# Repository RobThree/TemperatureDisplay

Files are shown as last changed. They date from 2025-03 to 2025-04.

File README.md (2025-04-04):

#  Temperature Display

Uses an Wemos D1 mini with a GXHT30 I²C temperature & humidity sensor and a SSD1306 I²C 0.96" OLED display.

This project supports OTA updates, uses the WiFi manager to configure the WiFi and provides a REST API to get the temperature and humidity as JSON. The readings (and display) are updated every 2 seconds (by default, configurable) and also output to serial.

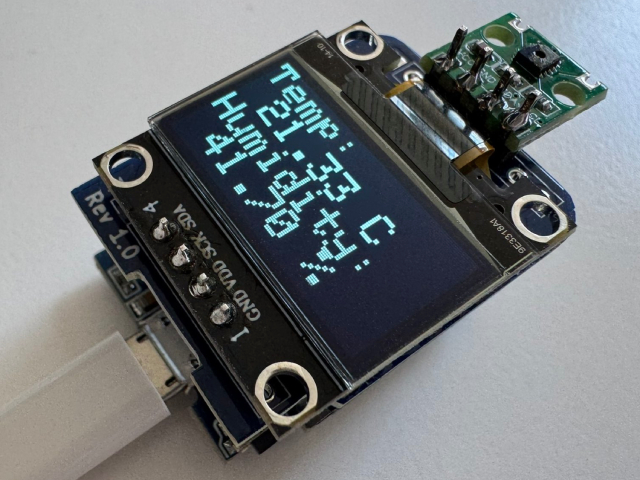
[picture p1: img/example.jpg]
Example


## Hardware

You'll need:

* [Wemos D1 mini or clone](https://aliexpress.com/w/wholesale-wemos-d1-mini.html)
* [GXHT30 I²C temperature & humidity sensor module](https://aliexpress.com/w/wholesale-GXHT30-module.html)
* [SSD1306 I²C 0.96" OLED display](https://aliexpress.com/w/wholesale-SSD1306-0.96%22.html)
* 2x [2.54mm female header 8 pins](https://aliexpress.com/w/wholesale-2.54mm-female-header-8-pins.html)
* 2x 8 pin and 2x 4 pin [2.54mm pin headers](https://aliexpress.com/w/wholesale-single-row-male-2.54mm.html)

All of these components are readily available at the time of writing, you should be able to easily source them.

### PCB

The [`pcb`](/pcb/) directory contains the KiCad (9.0) design files for the Wemos D1 mini shield PCB. [PCBWay](https://www.pcbway.com/) reached out to me and was kind enough to support this project. The project is available at [PCBWay's Shared Projects](https://www.pcbway.com/project/shareproject/Temperature_display_f0e459fd.html) for easy ordering.

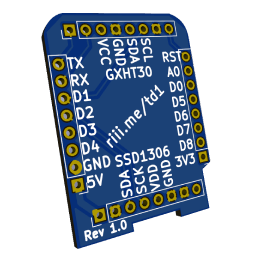
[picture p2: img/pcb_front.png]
PCB front
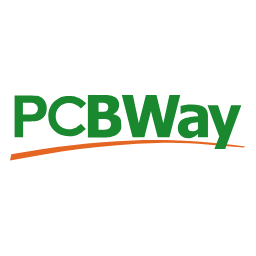
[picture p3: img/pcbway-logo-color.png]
PCBWay logo (https://www.pcbway.com/)
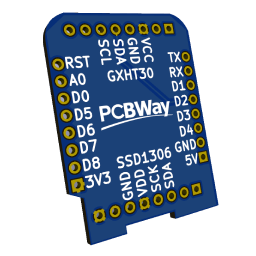
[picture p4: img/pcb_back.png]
PCB back
   

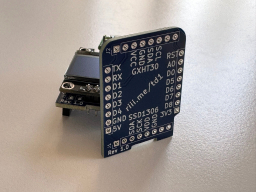
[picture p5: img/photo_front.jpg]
PCB front
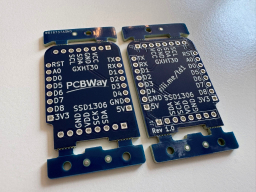
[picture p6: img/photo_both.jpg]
PCBWay logo
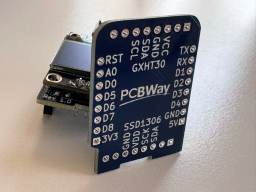
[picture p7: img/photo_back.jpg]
PCB back
   

For more pictures of the PCB and/or project see [the project page](https://www.pcbway.com/project/shareproject/Temperature_display_f0e459fd.html) or the [/img/PCBWay](/img/PCBWay/) directory. I would like to thank PCBWay again 🙏 Shipping was incredibly quick 🛫🛬 and the PCB is perfectly finished 👌

In a next iteration I'm hoping to integrate the GXHT30 on the shield, but being pretty new to PCB design this first iteration uses a module.

### DIY

Connect the GXHT30 and SSD1306 to the Wemos D1 mini's `3v3` pin, connect the grounds of all three modules. And connect `SDA` to `D2` (`GPIO4`) and `SCL` to `D1` (`GPIO5`). That's it. Done. Apparently some modules require 5V; if your display is glitching or not turning on, try connecting it to the 5V pin on the Wemos D1 mini. I power the project via the Wemos' onboard USB port but you should also be able to power it by directly powering the power pins.

```
                           +----------+        +------------------+
                           |  GXHT30  |        |     SSD1306      |
                           |    [X]   |        |                  |
                           |          |        |                  |
                           | V G  S S |        |    V  G  S  S    |
   +-----------------+     | C N  D C |        |    C  N  D  C    |
   |  Wemos D1 mini  |     | C D  A L |        |    C  D  A  K    |
   |    (ESP8266)    |     +----------+        +------------------+
   |                 |       | |  | |               |  |  |  |
   |              D1 |-------|-|--|-+---------------|--|--|--+
   |              D2 |-------|-|--+-----------------|--|--+
   |                 |       | |                    |  |
   |                 |       | |                    |  |
   |                 |       | |                    |  |
   |                 |       | |                    |  |
   |             GND |-------|-+--------------------|--+
+--| 3V3             |       |                      |
|  +-----------------+       |                      |
+----------------------------+----------------------+
```

### Tips on assembly:

* ⚠️ On some displays [there's a capacitor that can get quite close to the pins of this board](/img/pin.jpg). You might want to take a sidecutter and snip of a piece of the pin or use some kapton tape or some other means to isolate the pin. Make sure you check BOTH left and right side of the display!
* Solder the pinheaders/sockets **first**, and only **then** solder the display / temperature sensor. If you solder the display first you'll have a hard time reaching the pins connecting the board to the Wemos D1 mini
* When soldering the display to the board, [use a female header as a spacer](/img/spacer.jpg) for the perfect alignment.
* You don't _need_ to use male/female headers to connect the Wemos D1 mini to the PCB, you can use pins-only to make the device more compact. Just make sure you keep enough clearance!
* Don't forget to emjoy the peel-feel when removing the protective peel from the OLED 🤤

## Software

This is a PlatformIO project. I'm sure someone will help convert this to an Arduino IDE project, but it's not going to be me.

### How to get started

1. Open this folder in [PlatformIO for VSCode](https://platformio.org/platformio-ide)
2. Copy [`include/example_config.h`](include/example_config.h) to `include/config.h` and change the OTA update password and **devicename** (this one is optional)
3. Copy [`example_env_secrets.ini`](example_env_secrets.ini) to `env_secrets.ini` and set the same password for the `--auth` option
4. ⚠️ Make sure your [`platformio.ini`](platformio.ini) file has `default_envs` set to `d1_mini_serial`
5. Connect your USB cable to your device and the Wemos D1 mini
6. Compile the project and upload via (USB virtual) serial to your Wemos D1 mini
7. You should now be able to connect to a WiFi AP named after your **devicename** (see step 2); connect to it, set your WiFi credentials and save
8. The Wemos D1 mini should reboot and the OLED display should (shortly) show the IP; the display should show any other errors or problems as well
9. Next time you update you can use the OTA configuration (`default_envs` set to `d1_mini_ota` and the correct IP in `env_secrets.ini` at the `upload_port` entry), no more need for USB cables

### Once it's up and running

The display will show the temperature in °C or Fahrenheit (see `include/config.h`) and the humidity in %RH (Relative Humidity). If your sensor is way off you can fix this by setting `TEMPERATUREOFFSET` and/or `HUMIDITYOFFSET` in `include/config.h` and updating the device or, much easier, by using the web UI. The temperature and humidity will also be output to the serial port every time the sensor is read (see `UPDATEINTERVAL`) and when you use the `/read` endpoint of the REST API (e.g. `http://<deviceip>/read` [`GET`]) you'll get the readings as json:

```json
{
  "celsius": {
    "temperature": 22.81,
    "offset": -5
  },
  "fahrenheit": {
    "temperature": 73.058,
    "offset": -9
  },
  "humidity": {
    "relative_perc": 31.29,
    "relative_perc_offset": 8
  },
  "wifi": {
    "rssi": -48
  },
  "lastupdate": "1.62 seconds ago",
  "display": "c",
  "devicename": "MyDevice"
}
```

These values are only updated every time the sensor is read (again: see `UPDATEINTERVAL`). There is also a `/reset` endpoint ([`PUT`]) that will reboot the device.

Finally, the device also offers a user-friendly UI at the `/` endpoint (e.g. `http://<deivce-ip-here>/`) which updates every 5 seconds:

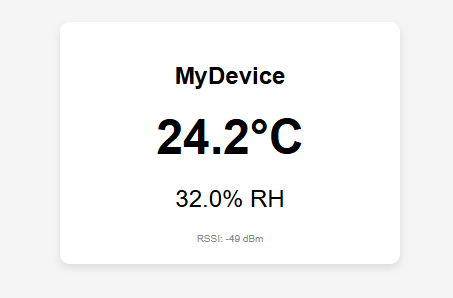
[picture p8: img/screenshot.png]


You can find the settings at `http://<deivce-ip-here>/settings` or by clicking the cog in the top right corner of the home screen. The settings screen allows you to adjust some values. Once your changed settings have been saved you can go back home by clicking the 'home' icon in the top right corner.

## Attribution

* PCB design based based on [Jérôme Labidurie](https://github.com/jerome-labidurie)'s [Wemos D1 mini Shield template for KiCad](https://github.com/jerome-labidurie/d1_mini_kicad)
* Logo from [SVG Repo](https://www.svgrepo.com/svg/179515/thermometer-temperature) (CC0 License)

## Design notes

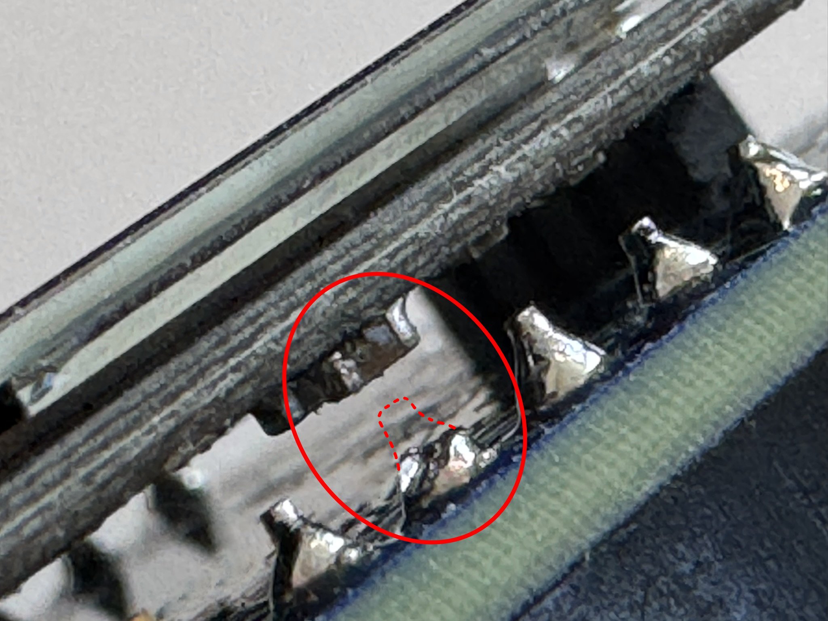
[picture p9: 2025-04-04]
img/pin.jpg

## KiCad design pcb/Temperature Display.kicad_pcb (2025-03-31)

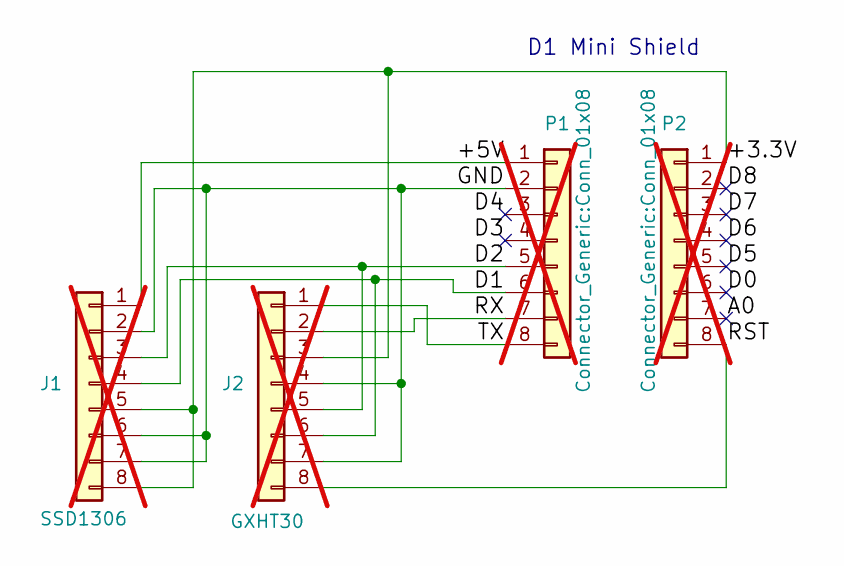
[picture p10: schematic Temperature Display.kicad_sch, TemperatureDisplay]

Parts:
J1: SSD1306; PinHeader_1x08_P2.54mm_Vertical; not fitted
J2: GXHT30; PinHeader_1x08_P2.54mm_Vertical; not fitted
P1, P2: Connector_Generic:Conn_01x08; PinHeader_1x08_P2.54mm_Vertical; not fitted

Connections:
/+3.3V: J1.5, J1.8, J2.3, P2.1
/+5V: J1.1, P1.1
/A0: P2.7
/D0: P2.6
/D1: J1.4, J2.6, P1.6
/D2: J1.3, J2.5, P1.5
/D3: P1.4
/D4: P1.3
/D5: P2.5
/D6: P2.4
/D7: P2.3
/D8: P2.2
/GND: J1.2, J1.6, J1.7, J2.4, J2.7, P1.2
/RST: J2.8, P2.8
/RX: J2.2, P1.7
/TX: J2.1, P1.8

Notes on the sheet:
D1 Mini Shield

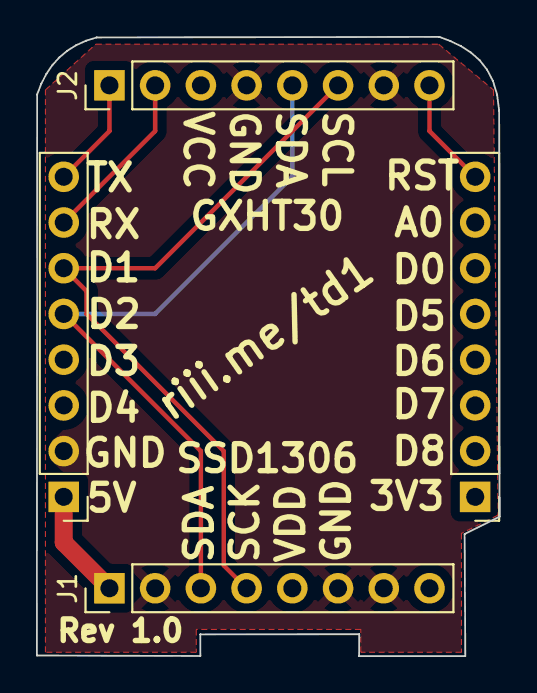
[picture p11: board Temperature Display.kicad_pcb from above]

Board: 2 copper layers, 25.7 x 34.4 mm, 4 parts (0 on the bottom side), 8 nets.

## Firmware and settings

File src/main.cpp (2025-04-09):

#include "appsettings.h"
#include "display.h"
#include "ota.h"
#include "sensor.h"
#include "settings.h"
#include "simplewifi.h"
#include "webserver.h"
#include <config.h>

// See include/example_config.h for configuration. Make sure you copy it
// to include/config.h and enter your configuration data there.

Logger logger(Serial);
OTA ota(logger);
SimpleWiFi wifi(logger);
Settings settings(logger);
Sensor sensor(logger);
Display display(logger, SCREEN_WIDTH, SCREEN_HEIGHT);
Webserver server(logger, LittleFS, HTTP_PORT);
SensorData lastreading;
AppSettings appsettings;

unsigned long previousMillis = 0; // Store the last time a measurement was taken

void setStatus(const char *status);
void handleReading();
void handleSettings();

void setup() {
    Serial.begin(SERIAL_BAUDRATE);

    display.begin();

    settings.onStatus(setStatus);
    settings.begin();

    settings.loadSettings(appsettings, [](AppSettings &defaults) {
        defaults.updateInterval = UPDATEINTERVAL;
        defaults.tempOffset = TEMPERATUREOFFSET;
        defaults.humidityOffset = HUMIDITYOFFSET;
        defaults.showFahrenheit = SHOWFAHRENHEIT ? true : false;
        strncpy(appsettings.deviceName, DEVICENAME, sizeof(appsettings.deviceName) - 1);
        defaults.deviceName[sizeof(appsettings.deviceName) - 1] = '\0'; // Ensure null termination
    });

    wifi.onStatus(setStatus);
    wifi.begin(PORTALTIMEOUT, WIFICONNECTTIMEOUT, WIFICONNECTRETRIES, appsettings.deviceName);

    sensor.begin();

    server.serveStatic("/", "/index.html");
    server.serveStatic("/css", "/main.css");
    server.serveStatic("/js", "/app.js");
    server.serveStatic("/favicon.ico", "/favicon.svg");
    server.serveStatic("/settings", "/settings.html");
    server.on("/read", HTTP_GET, handleReading);
    server.on("/settings", HTTP_POST, handleSettings);
    server.useDefaultEndpoints();
    server.onStatus(setStatus);
    server.begin();

    ota.onStatus(setStatus);
    ota.begin(appsettings.deviceName, OTAPASSWORD);

    setStatus(wifi.localIP().c_str());
    delay(2000);
}

void loop() {
    server.handleClient();
    ota.handle();
    wifi.ensureConnected();

    unsigned long currentMillis = millis(); // Get the current time

    // Check if it's time to take another measurement
    if (currentMillis - previousMillis >= appsettings.updateInterval) {
        previousMillis = currentMillis;

        SensorData reading = sensor.readData(appsettings.tempOffset, appsettings.humidityOffset);

        char buffer[64];
        snprintf(buffer, sizeof(buffer), "Temperature: %s, humidity: %s",
                 reading.getTemperatureDisplay(appsettings.showFahrenheit).c_str(),
                 reading.getHumidityDisplay().c_str());
        logger.info(String(buffer));

        display.showMeasurements(reading, appsettings.showFahrenheit);

        lastreading = reading; // Store the last reading
    }
}

void handleReading() {
    JsonDocument response;
    JsonObject celsiusnode = response["celsius"].to<JsonObject>();
    celsiusnode["temperature"] = lastreading.getTemperatureDisplayValue(false);
    celsiusnode["offset"] = lastreading.offset_c;
    JsonObject fahrenheitnode = response["fahrenheit"].to<JsonObject>();
    fahrenheitnode["temperature"] = lastreading.getTemperatureDisplayValue(true);
    fahrenheitnode["offset"] = lastreading.offset_f;
    JsonObject humiditynode = response["humidity"].to<JsonObject>();
    humiditynode["relative_perc"] = lastreading.getHumidityDisplayValue();
    humiditynode["relative_perc_offset"] = lastreading.humidity_offset;
    JsonObject wifinode = response["wifi"].to<JsonObject>();
    wifinode["rssi"] = WiFi.RSSI();

    char lastUpdateStr[32];
    unsigned long lastupdate = millis() - previousMillis;
    snprintf(lastUpdateStr, sizeof(lastUpdateStr), "%.2f seconds ago", lastupdate / 1000.0);
    response["lastupdate"] = lastUpdateStr;
    response["lastupdate_ms"] = lastupdate;
    response["display"] = appsettings.showFahrenheit ? "f" : "c";
    response["devicename"] = appsettings.deviceName;
    response["updateinterval"] = appsettings.updateInterval;
    server.sendJson(response);
}

void handleSettings() {
    AppSettings newsettings;
    JsonDocument response;
    response["status"] = "";
    JsonArray errors = response["errors"].to<JsonArray>();
    newsettings.updateInterval = server.arg("updateinterval").toInt();
    if (newsettings.updateInterval < 1000 || newsettings.updateInterval > 60000) {
        errors.add("Update interval must be between 1000 and 60000 ms");
    }
    newsettings.showFahrenheit = server.arg("showfahrenheit") == "f";

    newsettings.tempOffset = server.arg("tempoffset").toFloat();
    if (newsettings.tempOffset < -50 || newsettings.tempOffset > 50) {
        errors.add("Temperature offset must be between -50 and 50");
    }
    newsettings.humidityOffset = server.arg("humidityoffset").toFloat();
    if (newsettings.humidityOffset < -50 || newsettings.humidityOffset > 50) {
        errors.add("Humidity offset must be between -50 and 50");
    }
    strncpy(newsettings.deviceName, server.arg("devicename").c_str(), sizeof(newsettings.deviceName) - 1);
    newsettings.deviceName[sizeof(newsettings.deviceName) - 1] = '\0'; // Ensure null termination
    if (strlen(newsettings.deviceName) == 0 || strlen(newsettings.deviceName) > 31) {
        errors.add("Device name must be between 1 and 31 characters");
    }

    if (errors.size() == 0 && settings.saveSettings(newsettings, appsettings)) {
        response["status"] = "success";
    } else {
        response["status"] = "error";
    }
    server.sendJson(response);
}

void setStatus(const char *status) { display.setStatus(status); }

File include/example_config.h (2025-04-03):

// COPY THIS FILE AND RENAME IT TO "config.h" AND ENTER ALL YOUR CONFIGURATION DATA BELOW

#ifndef CONFIG_H
#define CONFIG_H

// These can all be set in the web interface and are used as defaults
#define UPDATEINTERVAL      2000    // Update interval in milliseconds
#define SHOWFAHRENHEIT      false   // Show Fahrenheit on display (celcius otherwise)
#define TEMPERATUREOFFSET   0.0     // Temperature offset / correction in Celcius
#define HUMIDITYOFFSET      0.0     // Humidity offset / correction in percentage
#define DEVICENAME          "devicename-here"

// These can only be set by re-flashing the firmware
#define OTAPASSWORD         "my_ota_secret"
#define PORTALTIMEOUT       90
#define WIFICONNECTTIMEOUT  10
#define WIFICONNECTRETRIES  255
#define HTTP_PORT           80
#define SERIAL_BAUDRATE     115200

#define SCREEN_WIDTH 128 // OLED display width, in pixels
#define SCREEN_HEIGHT 64 // OLED display height, in pixels
#endif

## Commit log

2025-03-20 Provide "Serial" and "OTA" configs. And wiring schema.
2025-03-25 Added KiCad PCB design
    [Temperature Display.kicad_pcb, Temperature Display.kicad_sch]
2025-03-25 PCB cleanup / optimization and silkscreen adjustments
    [Temperature Display.kicad_pcb]
2025-03-25 Update README, added software chapter, add PCB images.
2025-03-25 Typo 🤦‍♂️
2025-03-26 More PCB optimization, minor README fixes
    [Temperature Display.kicad_pcb, Temperature Display.kicad_sch]
2025-03-26 Final rev 1.0, ordered at PCBWay
    [Temperature Display.kicad_pcb]
2025-03-31 Cleanup. Add RSSI to json. PCB is blue.
    [Temperature Display.kicad_pcb]
2025-04-03 Fix bug in fahrenheit offset calculation.
    [main.cpp]
2025-04-03 Added photos of actual PCB by PCBWay.
2025-04-04 Added helptext, fixed secondary button hover highlight.
2025-04-04 Added assembly tips
2025-04-09 Refactor and organize code structure (#1)
    * Move stuff to separate files
    * More splitting to separate files
    * Format documents
    * More cleanup
    * Proper naming for private variables
    * Better naming
    * Fix some C/F confusion introduced by CoPilot
    * Minor cleanup & refactoring
    * Cleanup HTML, add spinner on settingspage while loading settings
    * Properly initialize display
    * More status on display
    [main.cpp]
